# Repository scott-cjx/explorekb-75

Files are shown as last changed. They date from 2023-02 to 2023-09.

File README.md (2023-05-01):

# explorekb-75
an open source 75% layout keyboard project as a start to my exploration in my keyboard making journey.

## Changelog

<ul>

<li>
Rev 4

Due to conflict of space between Controller Board and plate, controller board is shifted, allowing for plate to cover full length of Keyboard PCB.

Keyboard PCB:
- Shifted Blackpill Controller Board to the edge of the keyboard PCB, cut-out Keyboard PCB to allow for Blackpill to solder directly onto keyboard PCB with the USB port be like a center-mount USB on the keyboard PCB.
- Rotated OLED display 180 degrees. (now facing down)

Plate:

- WIP

</li>

<li>
Rev 3 

Keyboard PCB:
- Reverted back to using development board as controller, specifically using WeAct Studio Blackpill STM32F401 Controller Board.
- Tweaked layout to have 15 keys on ROW 0, including last 2 columns, COL 13 and 14 to be EC11 rotary encoders.
- Changed to have all diodes be BAT54C.
- Added OLED screen. (facing up)

Plate: <br>
Due to conflict of space between Controller Board and plate, the plate is unable to cover full length of Keyboard PCB, 3d printing the plate is then the safer option.

- Due to the change in layout from Rev 2 to Rev 3, <b> Rev 2 plates are NOT compatible with Rev 3 Keyboard PCB</b>.

</li>

<li>
Rev 2

Keyboard PCB:

Plate:

</li>

</ul>

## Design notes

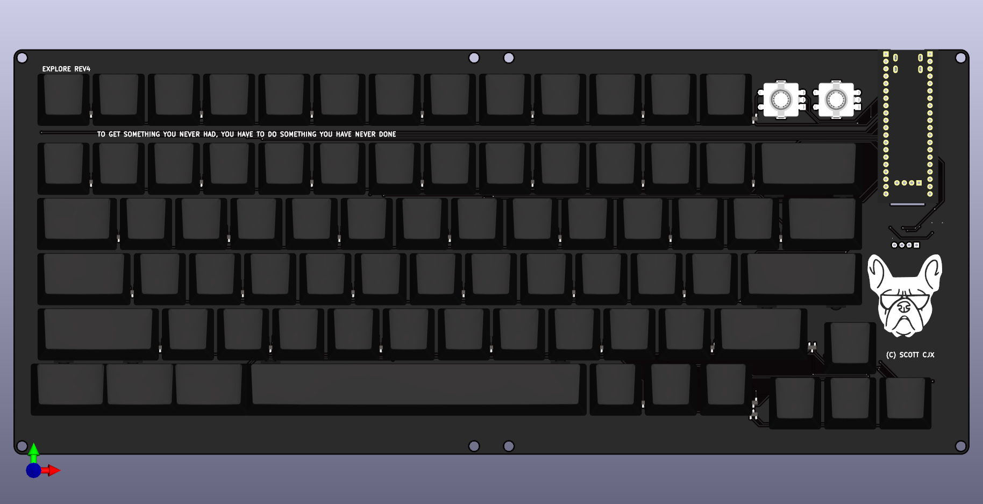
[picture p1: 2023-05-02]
hardware/renders/explorekb-rev4/explorekb-rev4-front.png

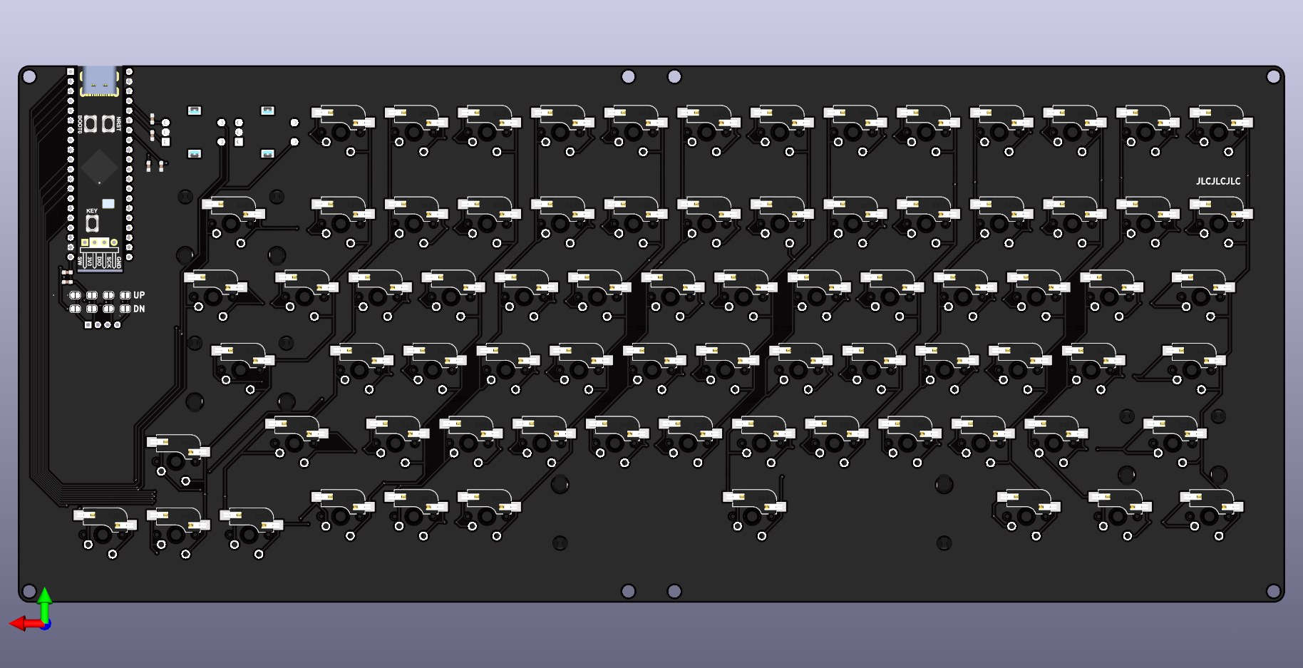
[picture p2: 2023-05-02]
hardware/renders/explorekb-rev4/explorekb-rev4-back.png

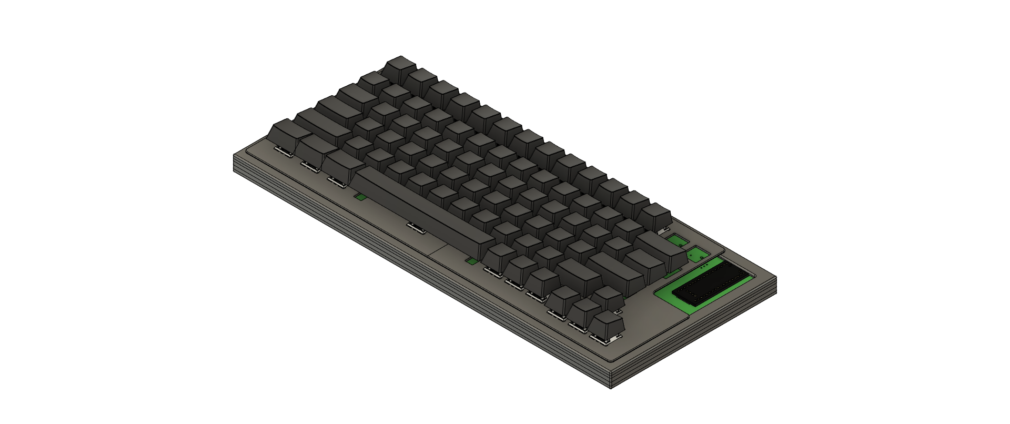
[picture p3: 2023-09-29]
hardware/renders/explorekb-rev4/explorekb-rev4-full (rev3 plate).png

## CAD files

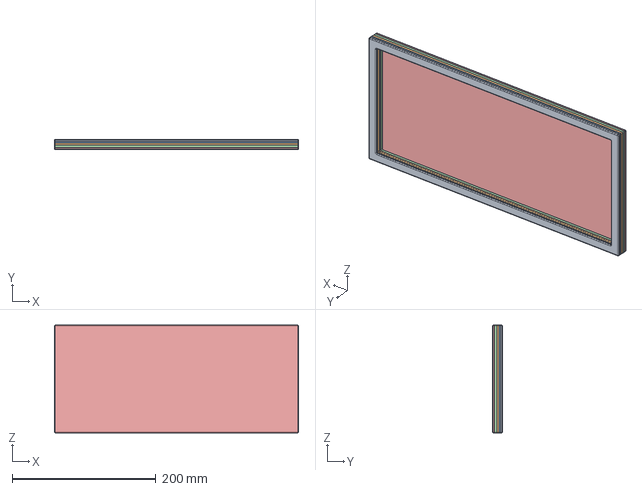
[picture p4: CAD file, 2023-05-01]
hardware/case/rev3/v1/explore-rev3-case-v1_full.step
340.0 x 14.0 x 150.0 mm

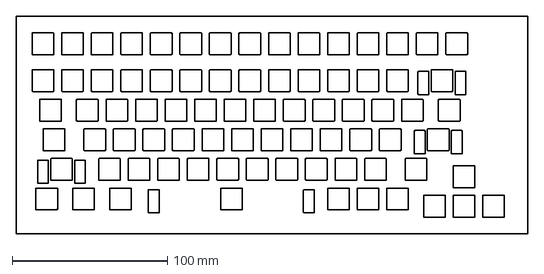
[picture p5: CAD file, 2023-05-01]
hardware/plate/initial/explore75-3_pcb_full.dxf
330.0 x 140.0 mm

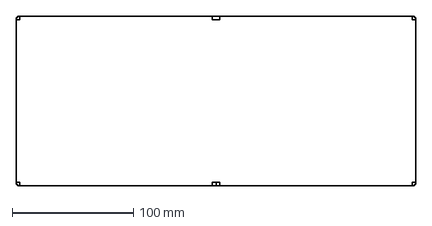
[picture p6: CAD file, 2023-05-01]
hardware/plate/initial/explore75-3_pcb_outline_curved.dxf
330.0 x 140.0 mm

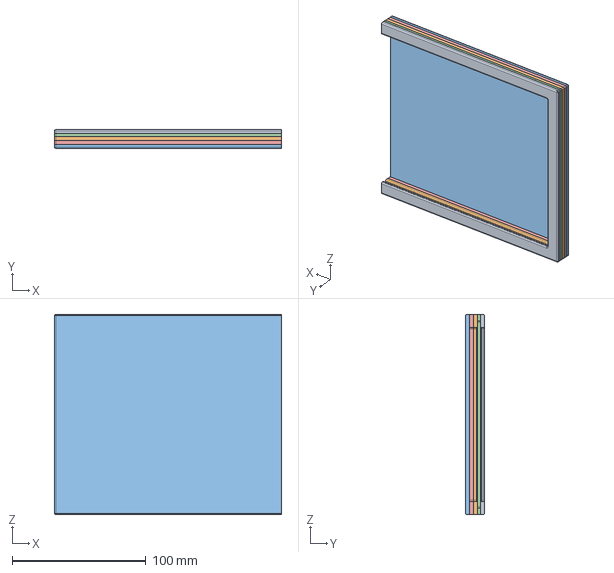
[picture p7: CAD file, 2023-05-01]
hardware/case/rev3/v1/explore-rev3-case-v1_sym-half.step
170.0 x 14.0 x 150.0 mm

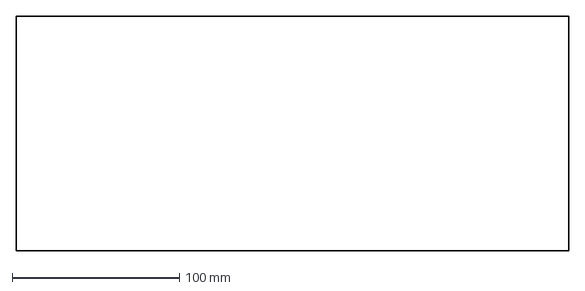
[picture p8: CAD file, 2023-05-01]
hardware/plate/initial/explore75-3_pcb_outline.dxf
330.0 x 140.0 mm

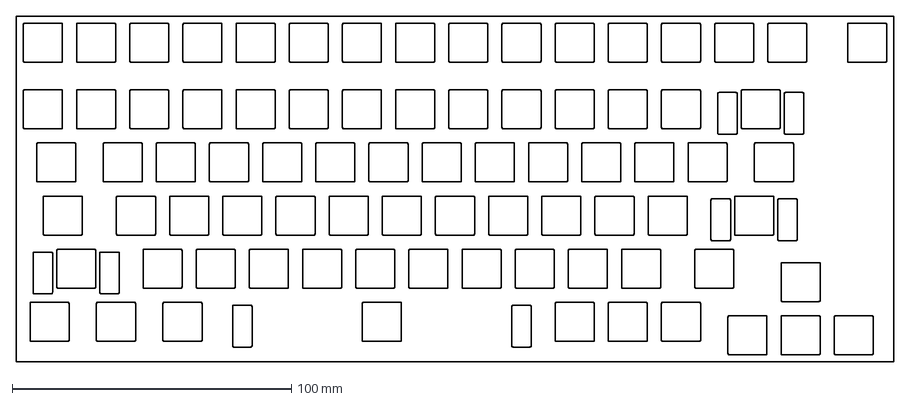
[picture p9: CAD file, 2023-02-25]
hardware/plate/initial/plate-2023-02-04T09_57_32.388Z.dxf
314.3 x 123.8 mm

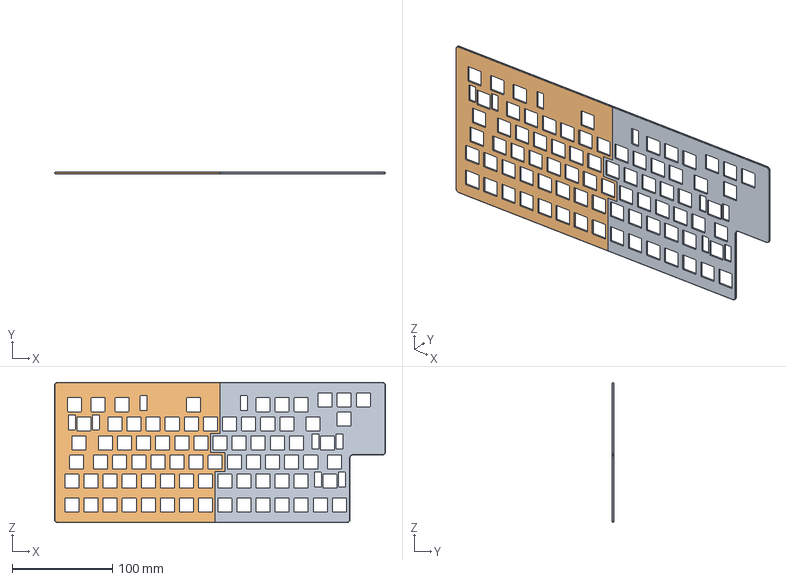
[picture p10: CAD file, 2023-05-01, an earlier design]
hardware/plate/explore-rev3/v1-3d-print/explore-rev3-plate-v1_full.step
330.0 x 1.50 x 140.0 mm

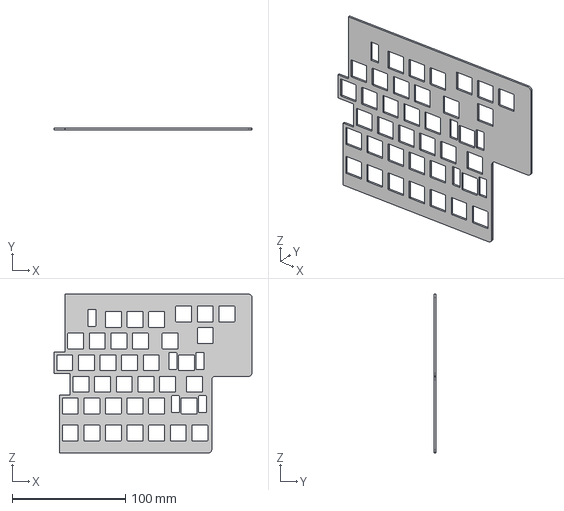
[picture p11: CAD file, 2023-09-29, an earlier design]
hardware/plate/explore-rev3/v1-3d-print/explore-rev3-plate-v1_right.step
174.5 x 1.50 x 140.0 mm

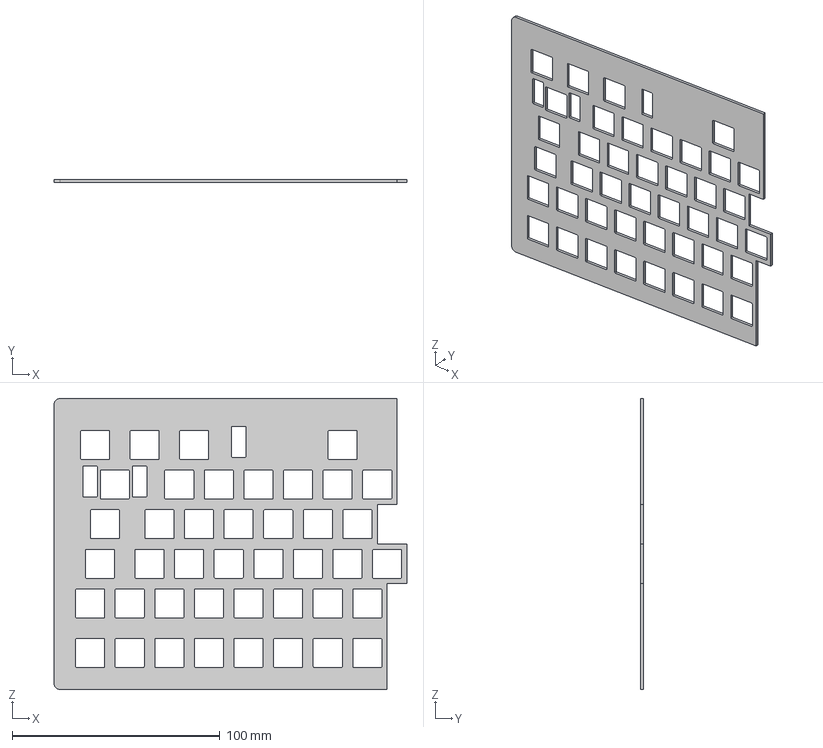
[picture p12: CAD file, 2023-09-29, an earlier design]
hardware/plate/explore-rev3/v1-3d-print/explore-rev3-plate-v1_left.step
169.8 x 1.50 x 140.0 mm

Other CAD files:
hardware/plate/initial/plate-2023-02-04T09_57_32.388Z v5.step
hardware/case/rev3/v1/explore-rev3-case-v1_sym-half.f3d
hardware/case/rev3/v1/explore-rev3-case-v1_sym-half.stl
hardware/plate/explore-rev3/v1-3d-print/explore-rev3-plate-v1_full.f3d
hardware/plate/explore-rev3/v1-3d-print/explore-rev3-plate-v1_left.f3d
hardware/plate/explore-rev3/v1-3d-print/explore-rev3-plate-v1_left.stl
hardware/plate/explore-rev3/v1-3d-print/explore-rev3-plate-v1_right.f3d
hardware/plate/explore-rev3/v1-3d-print/explore-rev3-plate-v1_right.stl
hardware/plate/initial/explore75-3_pcb.f3d

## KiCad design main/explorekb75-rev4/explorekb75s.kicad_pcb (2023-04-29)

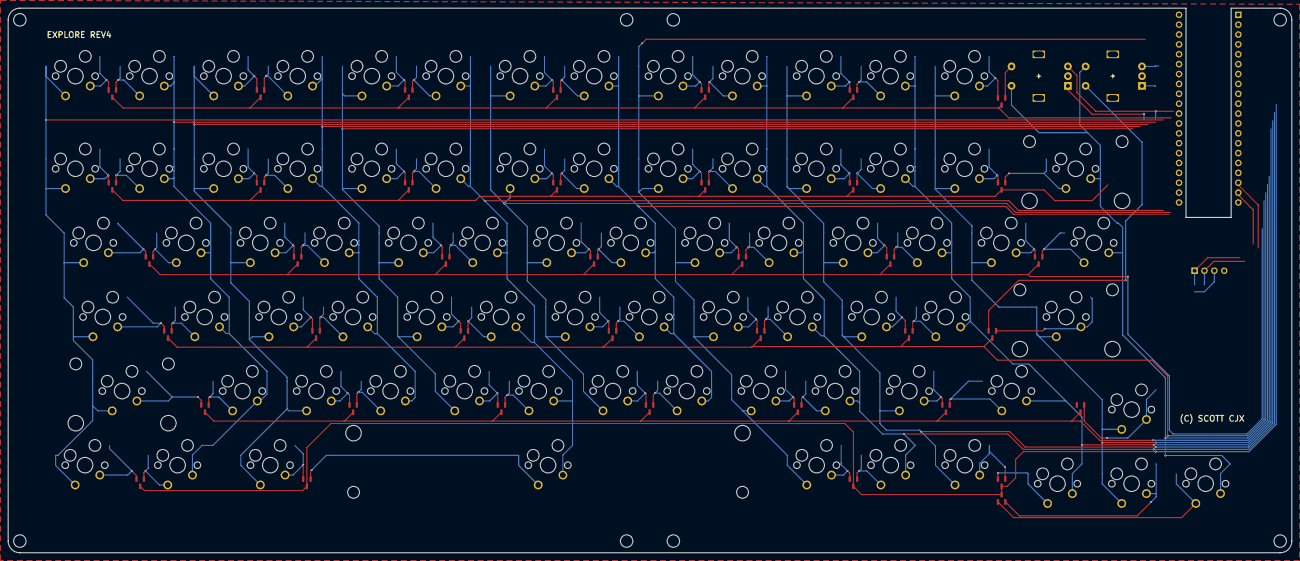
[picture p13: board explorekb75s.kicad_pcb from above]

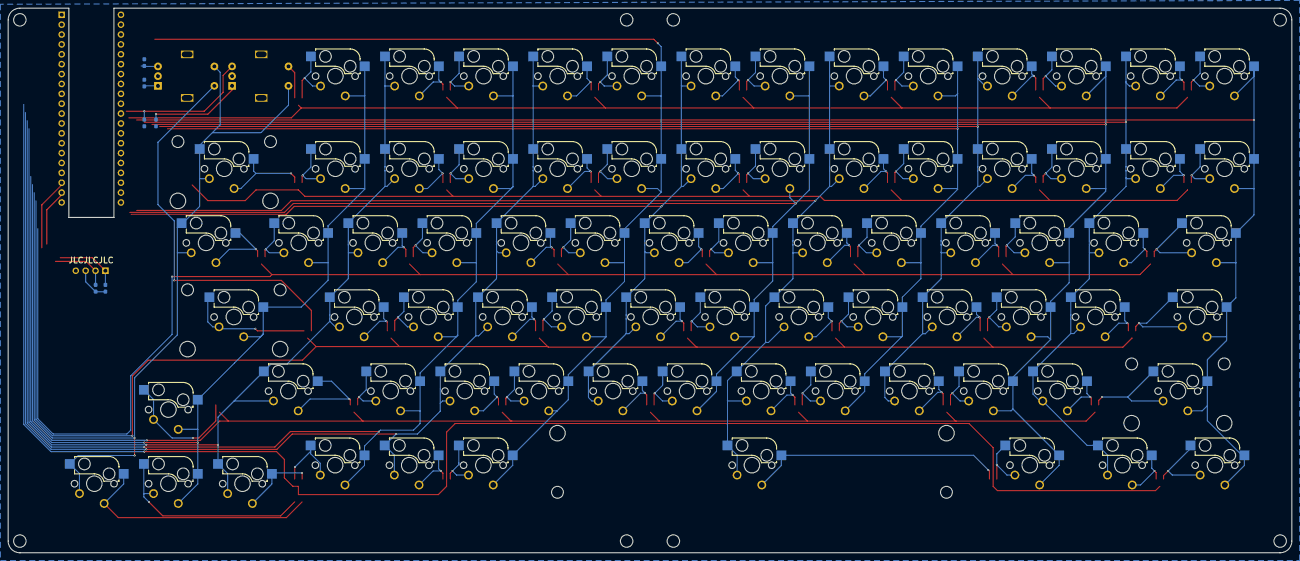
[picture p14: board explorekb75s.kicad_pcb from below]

Board: 2 copper layers, 330.0 x 140.0 mm, 131 parts (7 on the bottom side), 107 nets.

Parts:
C1, C2, C3, C4: 100n; C_0603_1608Metric_Pad1.08x0.95mm_HandSolder
D1, D2, D3, D4, D5, D6, D7, D8, D9, D10, D11, D12, D13, D14, D15, D16, D17, D18, D19, D20, D21, D22, D23, D24, D25, D26, D27, D28, D29, D30, D31, D32, D33, D34, D35, D36, D37, D38, D39, D40: BAT54C; SOT-23
R1, R2: 4k7; C_0603_1608Metric_Pad1.08x0.95mm_HandSolder
STAB1, STAB2, STAB3: Stabilizer_MX_2u
STAB4: Stabilizer_Cherry_MX_6.25u
SW1, SW2, SW3, SW4, SW5, SW6, SW7, SW8, SW9, SW10, SW11, SW12, SW13, SW16, SW17, SW18, SW19, SW20, SW21, SW22, SW23, SW24, SW25, SW26, SW27, SW28, SW29, SW30, SW31, SW32, SW33, SW34, SW35, SW36, SW37, SW38, SW39, SW40, SW41, SW42, SW43, SW44, SW45, SW46, SW47, SW48, SW49, SW50, SW51, SW52, SW53, SW54, SW55, SW56, SW57, SW58, SW59, SW60, SW61, SW62, SW63, SW64, SW65, SW66, SW67, SW68, SW69, SW70, SW71, SW72, SW73, SW74, SW75, SW76, SW77, SW78, SW79: SW_SPST; MX_HS_Optional
SW14, SW15: RotaryEncoder_Switch; RotaryEncoder_Alps_EC11E-Switch_Vertical_H20mm
U1: YAAJ_WeAct_BlackPill_Part_Like; YAAJ_WeAct_BlackPill_2
U2: SSD1306; SSD1306_128X32

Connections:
+3V3: R1.1, R2.1, U1.20 (3V3), U2.3 (VCC)
/COL 0: SW1.2 (B), SW16.2 (B), SW30.2 (B), SW44.2 (B), SW57.2 (B), SW70.2 (B), U1.32 (PA6)
/COL 1: SW2.1 (A), SW17.1 (A), SW31.1 (A), SW45.1 (A), SW58.1 (A), SW71.1 (A), U1.31 (PA5)
/COL 2: SW3.2 (B), SW18.2 (B), SW32.2 (B), SW46.2 (B), SW59.2 (B), SW72.2 (B), U1.30 (PA4)
/COL 3: SW4.1 (A), SW19.1 (A), SW33.1 (A), SW47.1 (A), SW60.1 (A), U1.29 (PA3)
/COL 4: SW5.2 (B), SW20.2 (B), SW34.2 (B), SW48.2 (B), SW61.2 (B), U1.28 (PA2)
/COL 5: SW6.1 (A), SW21.1 (A), SW35.1 (A), SW49.1 (A), SW62.1 (A), SW73.1 (A), U1.26 (PA0)
/COL 6: SW7.2 (B), SW22.2 (B), SW36.2 (B), SW50.2 (B), SW63.2 (B), U1.24 (PC15)
/COL 7: SW8.1 (A), SW23.1 (A), SW37.1 (A), SW51.1 (A), SW64.1 (A), U1.23 (PC14)
/COL 8: SW9.2 (B), SW24.2 (B), SW38.2 (B), SW52.2 (B), SW65.2 (B), SW74.2 (B), U1.1 (PB12)
/COL 9: SW10.1 (A), SW25.1 (A), SW39.1 (A), SW53.1 (A), SW66.1 (A), SW75.1 (A), U1.3 (PB14)
/COL 10: SW11.2 (B), SW26.2 (B), SW40.2 (B), SW54.2 (B), SW67.2 (B), SW76.2 (B), U1.4 (PB15)
/COL 11: SW12.1 (A), SW27.1 (A), SW41.1 (A), SW55.1 (A), SW68.1 (A), SW77.1 (A), U1.5 (PA8)
/COL 12: SW13.2 (B), SW28.2 (B), SW42.2 (B), SW56.2 (B), SW69.2 (B), SW78.2 (B), U1.10 (PA15)
/COL 13: SW14.S2, SW15.S1, SW29.1 (A), SW43.1 (A), SW79.1 (A), U1.12 (PB4)
/Key Matrix/ROT1_2: D7.1, SW14.S1
/Key Matrix/ROT2_2: D28.2, SW15.S2
/ROT1_A: C1.1, SW14.B, U1.35 (PB1)
/ROT1_B: C2.1, SW14.A, U1.34 (PB0)
/ROT2_A: C3.1, SW15.B, U1.37 (PB10)
/ROT2_B: C4.1, SW15.A, U1.36 (PB2)
/ROW 0: D1.3, D2.3, D3.3, D4.3, D5.3, D6.3, D7.3, U1.33 (PA7)
/ROW 1: D8.3, D9.3, D10.3, D11.3, D12.3, D13.3, D14.3, U1.27 (PA1)
/ROW 2: D15.3, D16.3, D17.3, D18.3, D19.3, D20.3, D21.3, U1.16 (PB8)
/ROW 3: D22.3, D23.3, D24.3, D25.3, D26.3, D27.3, D28.3, U1.13 (PB5)
/ROW 4: D29.3, D30.3, D31.3, D32.3, D33.3, D34.3, D35.3, U1.11 (PB3)
/ROW 5: D36.3, D37.3, D38.3, D39.3, D40.3, U1.2 (PB13)
/SCL1: R2.2, U1.14 (PB6), U2.2 (SCK)
/SDA1: R1.2, U1.15 (PB7), U2.1 (SDA)
GND: C1.2, C2.2, C3.2, C4.2, SW14.C, SW15.C, U1.19 (GND), U1.39 (GND), U2.4 (GND)
unnamed: D1.1, SW2.2 (B)
unnamed: D1.2, SW1.1 (A)
unnamed: D2.1, SW4.2 (B)
unnamed: D2.2, SW3.1 (A)
unnamed: D3.1, SW6.2 (B)
unnamed: D3.2, SW5.1 (A)
unnamed: D4.1, SW8.2 (B)
unnamed: D4.2, SW7.1 (A)
unnamed: D5.1, SW10.2 (B)
unnamed: D5.2, SW9.1 (A)
unnamed: D6.1, SW12.2 (B)
unnamed: D6.2, SW11.1 (A)
unnamed: D7.2, SW13.1 (A)
unnamed: D8.1, SW17.2 (B)
unnamed: D8.2, SW16.1 (A)
unnamed: D9.1, SW19.2 (B)
unnamed: D9.2, SW18.1 (A)
unnamed: D10.1, SW21.2 (B)
unnamed: D10.2, SW20.1 (A)
unnamed: D11.1, SW23.2 (B)
unnamed: D11.2, SW22.1 (A)
unnamed: D12.1, SW25.2 (B)
unnamed: D12.2, SW24.1 (A)
unnamed: D13.1, SW27.2 (B)
unnamed: D13.2, SW26.1 (A)
unnamed: D14.1, SW29.2 (B)
unnamed: D14.2, SW28.1 (A)
unnamed: D15.1, SW31.2 (B)
unnamed: D15.2, SW30.1 (A)
unnamed: D16.1, SW33.2 (B)
unnamed: D16.2, SW32.1 (A)
unnamed: D17.1, SW35.2 (B)
unnamed: D17.2, SW34.1 (A)
unnamed: D18.1, SW37.2 (B)
unnamed: D18.2, SW36.1 (A)
unnamed: D19.1, SW39.2 (B)
unnamed: D19.2, SW38.1 (A)
unnamed: D20.1, SW41.2 (B)
unnamed: D20.2, SW40.1 (A)
unnamed: D21.1, SW43.2 (B)
unnamed: D21.2, SW42.1 (A)
unnamed: D22.1, SW45.2 (B)
unnamed: D22.2, SW44.1 (A)
unnamed: D23.1, SW47.2 (B)
unnamed: D23.2, SW46.1 (A)
unnamed: D24.1, SW49.2 (B)
unnamed: D24.2, SW48.1 (A)
unnamed: D25.1, SW51.2 (B)
unnamed: D25.2, SW50.1 (A)
unnamed: D26.1, SW53.2 (B)
unnamed: D26.2, SW52.1 (A)
unnamed: D27.1, SW55.2 (B)
unnamed: D27.2, SW54.1 (A)
unnamed: D28.1, SW56.1 (A)
unnamed: D29.1, SW58.2 (B)
unnamed: D29.2, SW57.1 (A)
unnamed: D30.1, SW60.2 (B)
unnamed: D30.2, SW59.1 (A)
unnamed: D31.1, SW62.2 (B)
unnamed: D31.2, SW61.1 (A)
unnamed: D32.1, SW64.2 (B)
unnamed: D32.2, SW63.1 (A)
unnamed: D33.1, SW66.2 (B)
unnamed: D33.2, SW65.1 (A)
unnamed: D34.1, SW68.2 (B)
unnamed: D34.2, SW67.1 (A)
unnamed: D35.1, SW69.1 (A)
unnamed: D36.1, SW71.2 (B)
unnamed: D36.2, SW70.1 (A)
unnamed: D37.1, SW73.2 (B)
unnamed: D37.2, SW72.1 (A)
unnamed: D38.1, SW75.2 (B)
unnamed: D38.2, SW74.1 (A)
unnamed: D39.1, SW76.1 (A)
unnamed: D39.2, SW77.2 (B)
unnamed: D40.1, SW79.2 (B)
unnamed: D40.2, SW78.1 (A)

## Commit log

2023-02-25 added v1-square-edge
    [Controller.kicad_sch, explore75-3_pcb.f3d, explore75-3_pcb_full.dxf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]
2023-03-14 added init board and pcb
    [explore75-3_pcb_outline_curved.dxf, explorekb75.kicad_sch, key_matrix.kicad_sch]
2023-04-29 added rev 4
    [Controller.kicad_sch, EXPLORE75-3 Half-Case v1 v2.stl, Explore75-3 Case v1.step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]
2023-04-29 complete wiring for rev 4
    [explorekb75s.kicad_sch]
2023-05-01 added rev3 plate v1
    [explore-rev3-plate-v1_full.f3d, explore-rev3-plate-v1_full.step, explore-rev3-plate-v1_left.f3d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]
2023-05-01 refactored file structure
    [Explore75-3 Case v1.step, Explore75-3 HalfCase v1.step, explore-rev3-case-v1_full.step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]
2023-05-01 refactored paths
    [explorekb75s.kicad_sch, key_matrix.kicad_sch]
2023-05-01 use new kicad parts
2023-05-01 updated rev4 pcb
    [explorekb75.kicad_sch, explorekb75s.kicad_sch]
2023-05-25 added stl for rev3 plate-v1
    [explore-rev3-plate-v1_left.step, explore-rev3-plate-v1_left.stl, explore-rev3-plate-v1_right.step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]
2023-09-29 updated files
    [explorekb-rev4.kicad_sch, key_matrix.kicad_sch]
